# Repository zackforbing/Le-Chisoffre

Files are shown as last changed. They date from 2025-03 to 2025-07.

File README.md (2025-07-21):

# Le-Chisoffre

chiff riff with trackpad, mouseball or rotary support, now with hotswap

don't get mad at me if these don't work, they are untested. I have zero idea what I'm doing, and your yolo to jlc is not my problem

7/21/25 case probably complete. still have to prototype though. and export/upload the files. but hey pretty pictures

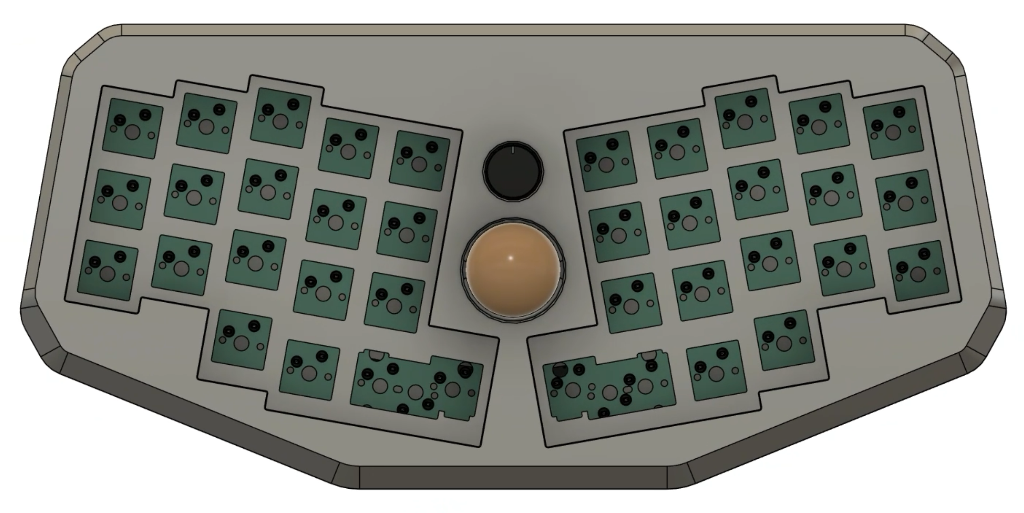
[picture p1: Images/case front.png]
case front

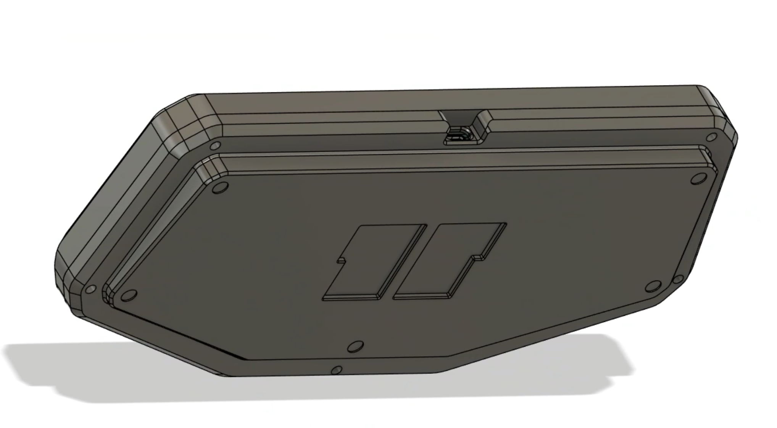
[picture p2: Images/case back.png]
case back

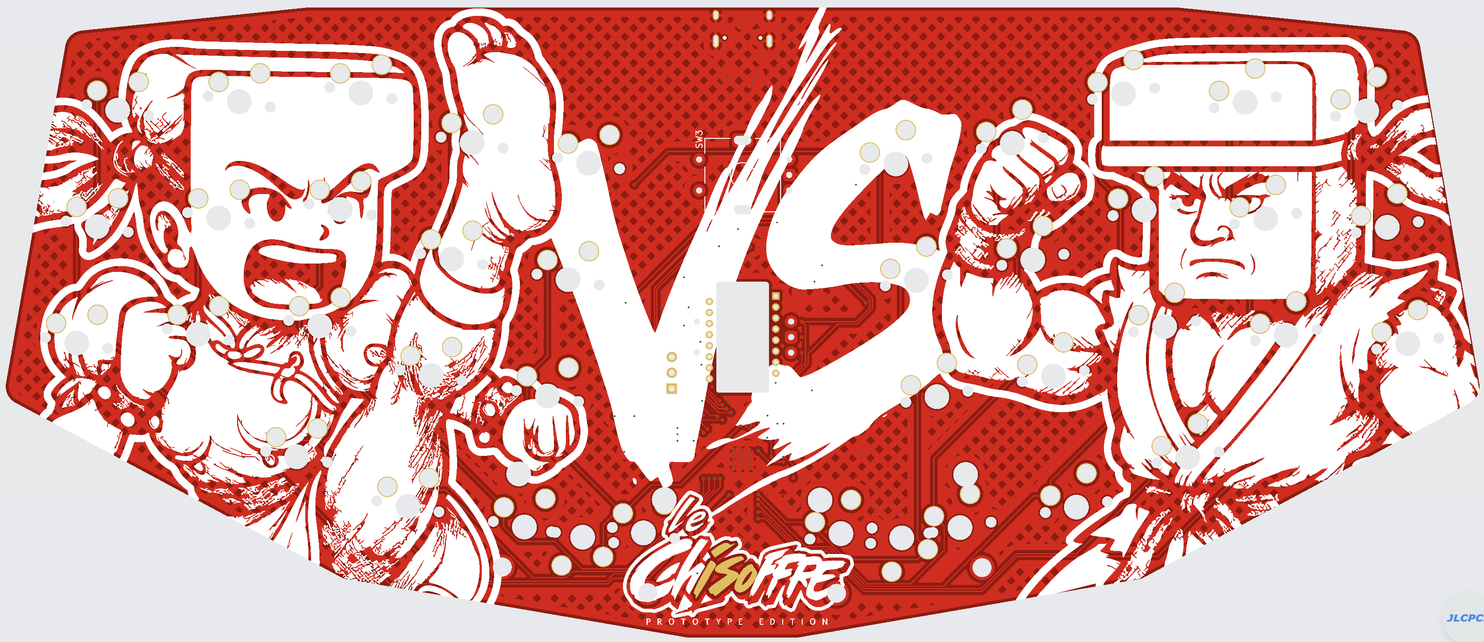
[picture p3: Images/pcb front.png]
pcb front

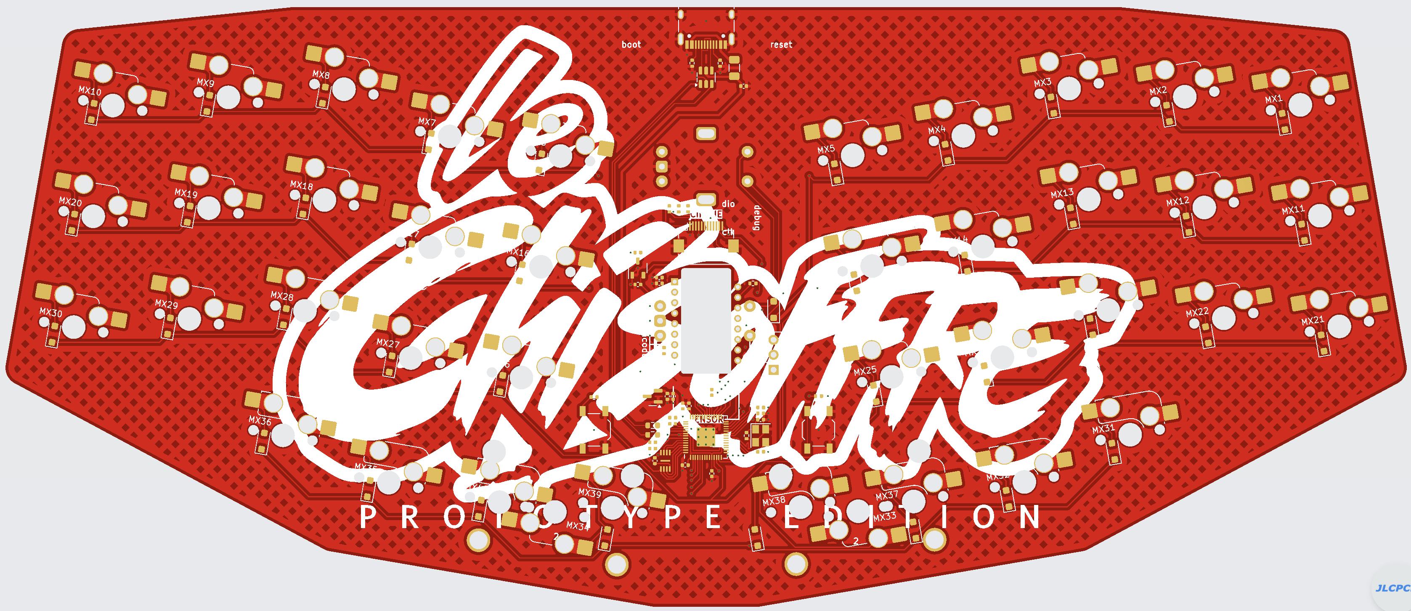
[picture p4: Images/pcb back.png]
pcb back


original readme preserved below

## Layout

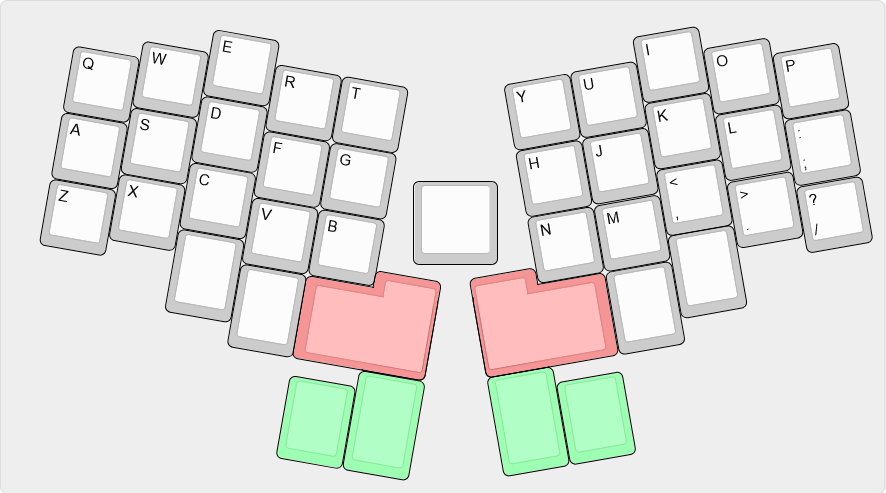
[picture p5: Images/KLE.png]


[Link](https://www.keyboard-layout-editor.com/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,%3B&@_y:-0.6399999999999997&x:0.25%3B&=N&=M&_x:1%3B&=%3E%0A.%3B&@_y:-0.75&x:4.25%3B&=%3F%0A%2F%2F%3B&@_y:-0.6200000000000001&x:2.25&a:7&h:1.25%3B&=%3B&@_y:-0.6299999999999999&x:1.25&h:1.25%3B&=%3B&@_y:0.22999999999999954&x:-0.75&c=%239cffb2&h:1.5%3B&=%3B&@_y:-0.75&x:0.25&h:1.25%3B&=)

## Todo

- [ ] order & test pcb
- [ ] create firmware
- [x] create case

## Disclaimer

Please note that this project is a work in progress with no guarantees of a working outcome. No-one involved in this project is responsible for any usage issues that may arise. However, feel free to edit, modify and otherwise utilise these files.

## License

This project is released under the GPL v3 License. Please refer to the LICENCE file.

## Credits

As always big thanks to the many people who helped me and inspired this board!

Any questions, contact Calvin0563 on Discord.

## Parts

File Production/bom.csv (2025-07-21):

Designator | Footprint | Quantity | Value | LCSC Part #
C1 | 0402 | 1 | 100n | C1525
C10, C11, C12, C13, C14, C15, C5, C6, C9 | 0402 | 9 | 100nF | C1525
C16, C17, C4, C8 | 0402 | 4 | 1uF | C52923
C18, C20, C21 | 0402 | 3 | 4u7 | C23733
C19 | 0402 | 1 | 100n | C307331
C2, C3 | 0402 | 2 | 22pF | C1555
C7 | 0402 | 1 | 10uF | C15525
D1, D10, D11, D12, D13, D14, D15, D16, D17, D18, D19, D2, D20, D21, D22, D23, D24, D25, D26, D27, D28, D29, D3, D30, D31, D32, D35, D36, D37, D38, D39, D4, D40, D41, D5, D6, D7, D8, D9 | D_SOD-123F | 39 | D_Small
F1 | 1206 | 1 | 500mA | C70076
IC1 | SON50P300X200X60-9N | 1 | W25Q16JVUXIQ | C2843335
J1 | USB_C_Receptacle_HRO_TYPE-C-31-M-12 | 1 | USB_C_Receptacle_USB2.0 | C165948
J2 | VIK_Cirque_Horizontal | 1 | VIK Cirque Connector | C88360
MX1, MX10, MX11, MX12, MX13, MX14, MX15, MX16, MX17, MX18, MX19, MX2, MX20, MX21, MX22, MX23, MX24, MX25, MX26, MX27, MX28, MX29, MX3, MX30, MX33, MX34, MX4, MX5, MX6, MX7, MX8, MX9 | flipped | 32 | MX_SW_solder
MX31, MX32, MX35, MX36, MX37, MX40 | flipped mx hs 1.25u vert | 6 | MX_SW_solder
MX38, MX39 | sw mx hs back 1.5 vert | 2 | MX_SW_solder
R10 | 0402 | 1 | 39 | C25164
R11, R9 | 0402 | 2 | 10k | C25744
R12, R13 | 0402 | 2 | 4k7 | C25900
R2 | 0402 | 1 | 1k | C25543
R3, R4 | 0402 | 2 | 5k1 | C25905
R5 | 0402 | 1 | 5.1k
R6 | 0402 | 1 | 1k | C11702
R7, R8 | 0603 | 2 | 27R | C25190
S1, S2 | STAB_MX_P_ISO | 2 | MX_stab
SW1 | SW_SPST_TL3342 | 1 | boot | C115351
SW2, SW3 | ROT_Alps_EC11E-Switch | 2 | RotaryEncoder_Switch
SWD1 | PinHeader_1x03_P2.54mm_Vertical | 1 | Conn_01x03_Female
SWR1 | SW_SPST_TL3342 | 1 | Reset
U1 | SOT-23-6 | 1 | USBLC6-2SC6 | C2827654
U2 | SOT-23 | 1 | XC6206PxxxMR-Regulator_Linear | C5446
U3 | RP2040-QFN-56 | 1 | RP2040 | C2040
U4 | SOT-23-3 | 1 | XC6206P202MR | C2891260
U5 | PMW3360 | 1 | PMW3360DM-T2QU_1
Y1 | Crystal_SMD_3225-4Pin_3.2x2.5mm | 1 | 12MHz | C9002

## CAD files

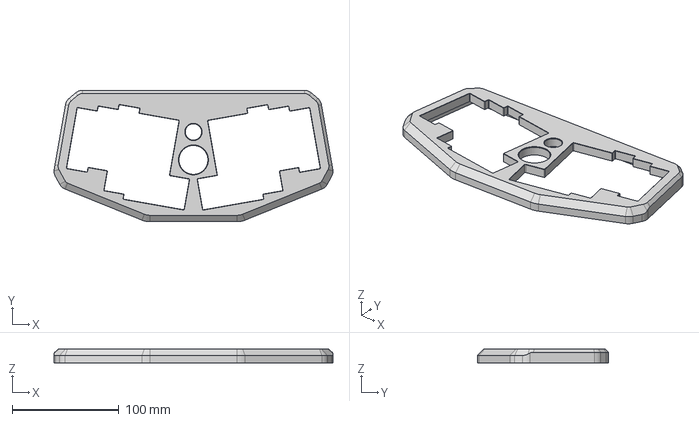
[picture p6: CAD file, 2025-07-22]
case/Le Chisoffre case revision v6 dual encoder top.step
260.8 x 122.9 x 13.0 mm

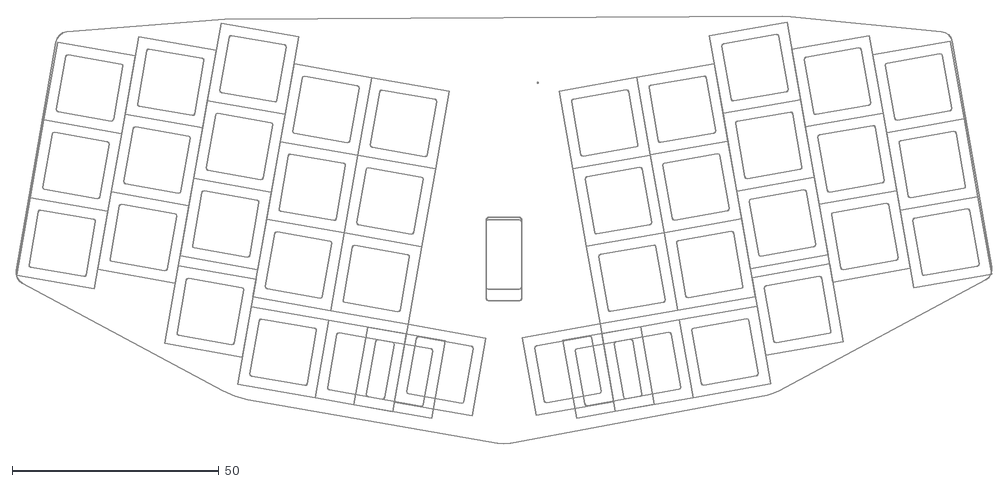
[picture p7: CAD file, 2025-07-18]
Images/Le Chisoffre-Edge_Cuts.dxf
235.8 x 103.3

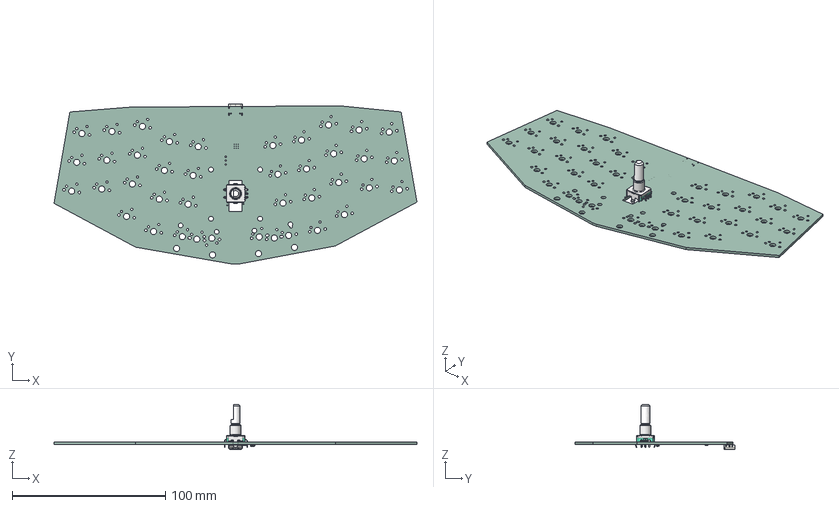
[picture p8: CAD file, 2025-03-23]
Project/Le Chisoffre.step
236.5 x 104.6 x 29.6 mm
(Unsaved)
W25X40CLUXIG TR
USB_C_Receptacle_16P_TopMnt_Horizontal_GCT_USB4105-xx-A
SOT_23
Le Chisoffre_PCB

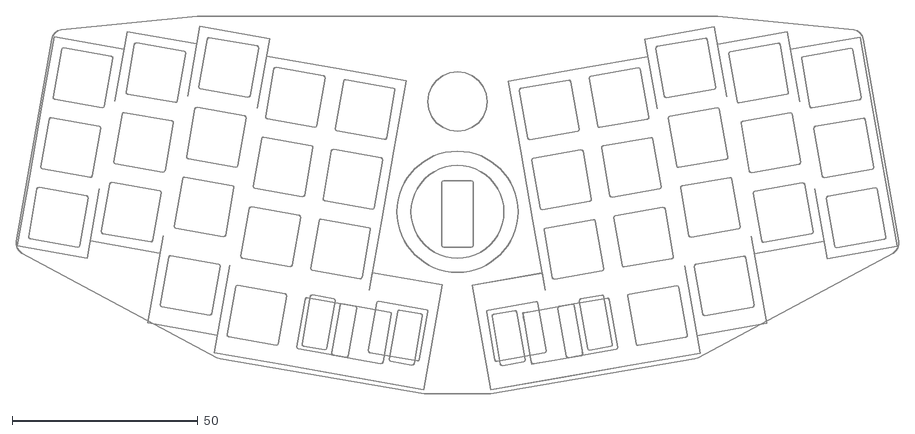
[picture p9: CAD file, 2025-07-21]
Project/Production/Le Chisoffre-Edge_Cuts.dxf
237.4 x 101.6

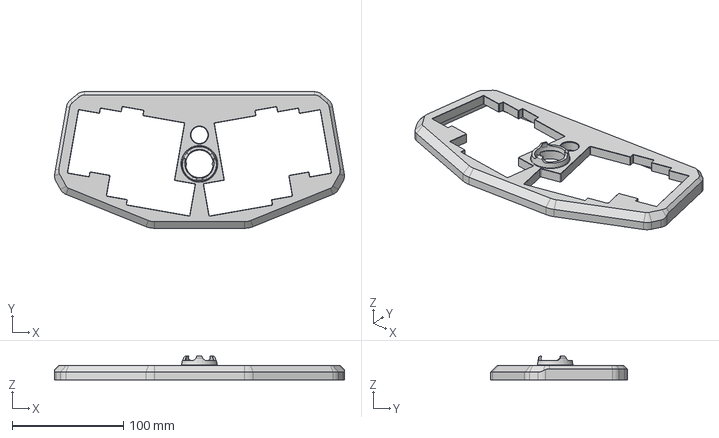
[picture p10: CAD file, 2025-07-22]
case/Le Chisoffre case revision v6 top.step
260.8 x 122.9 x 21.5 mm

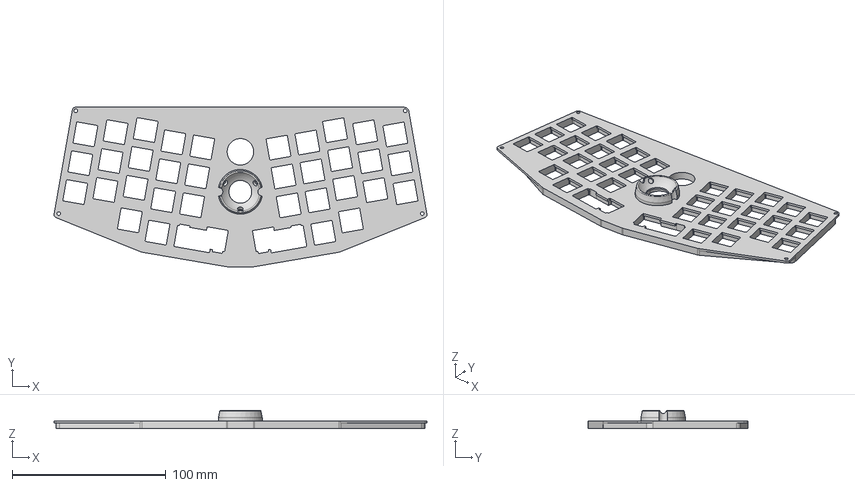
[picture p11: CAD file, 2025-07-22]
case/Le Chisoffre case revision v6 plate.step
242.2 x 103.6 x 11.8 mm

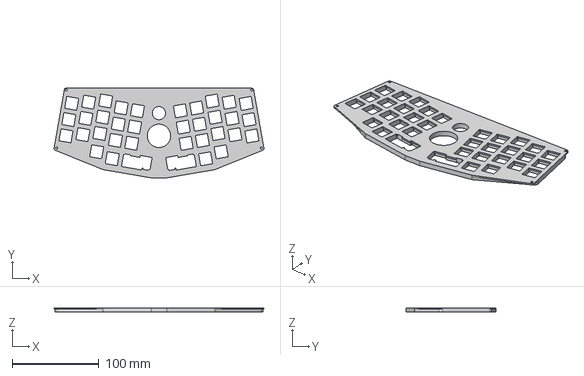
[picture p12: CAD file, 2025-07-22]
case/Le Chisoffre case revision v6 dual encoder plate.step
242.2 x 103.6 x 5.00 mm

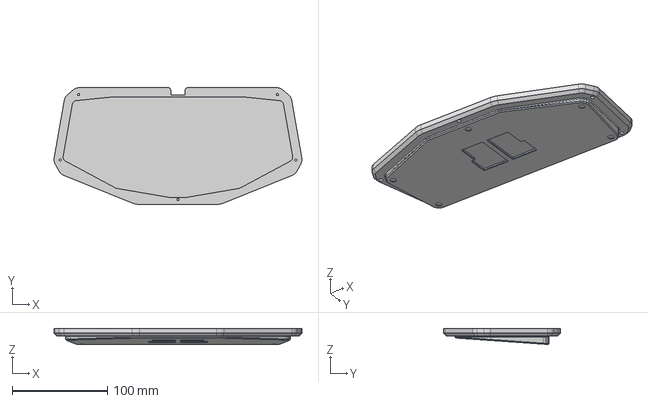
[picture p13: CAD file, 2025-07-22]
case/Le Chisoffre case revision v6 bottom.step
260.8 x 122.9 x 16.8 mm

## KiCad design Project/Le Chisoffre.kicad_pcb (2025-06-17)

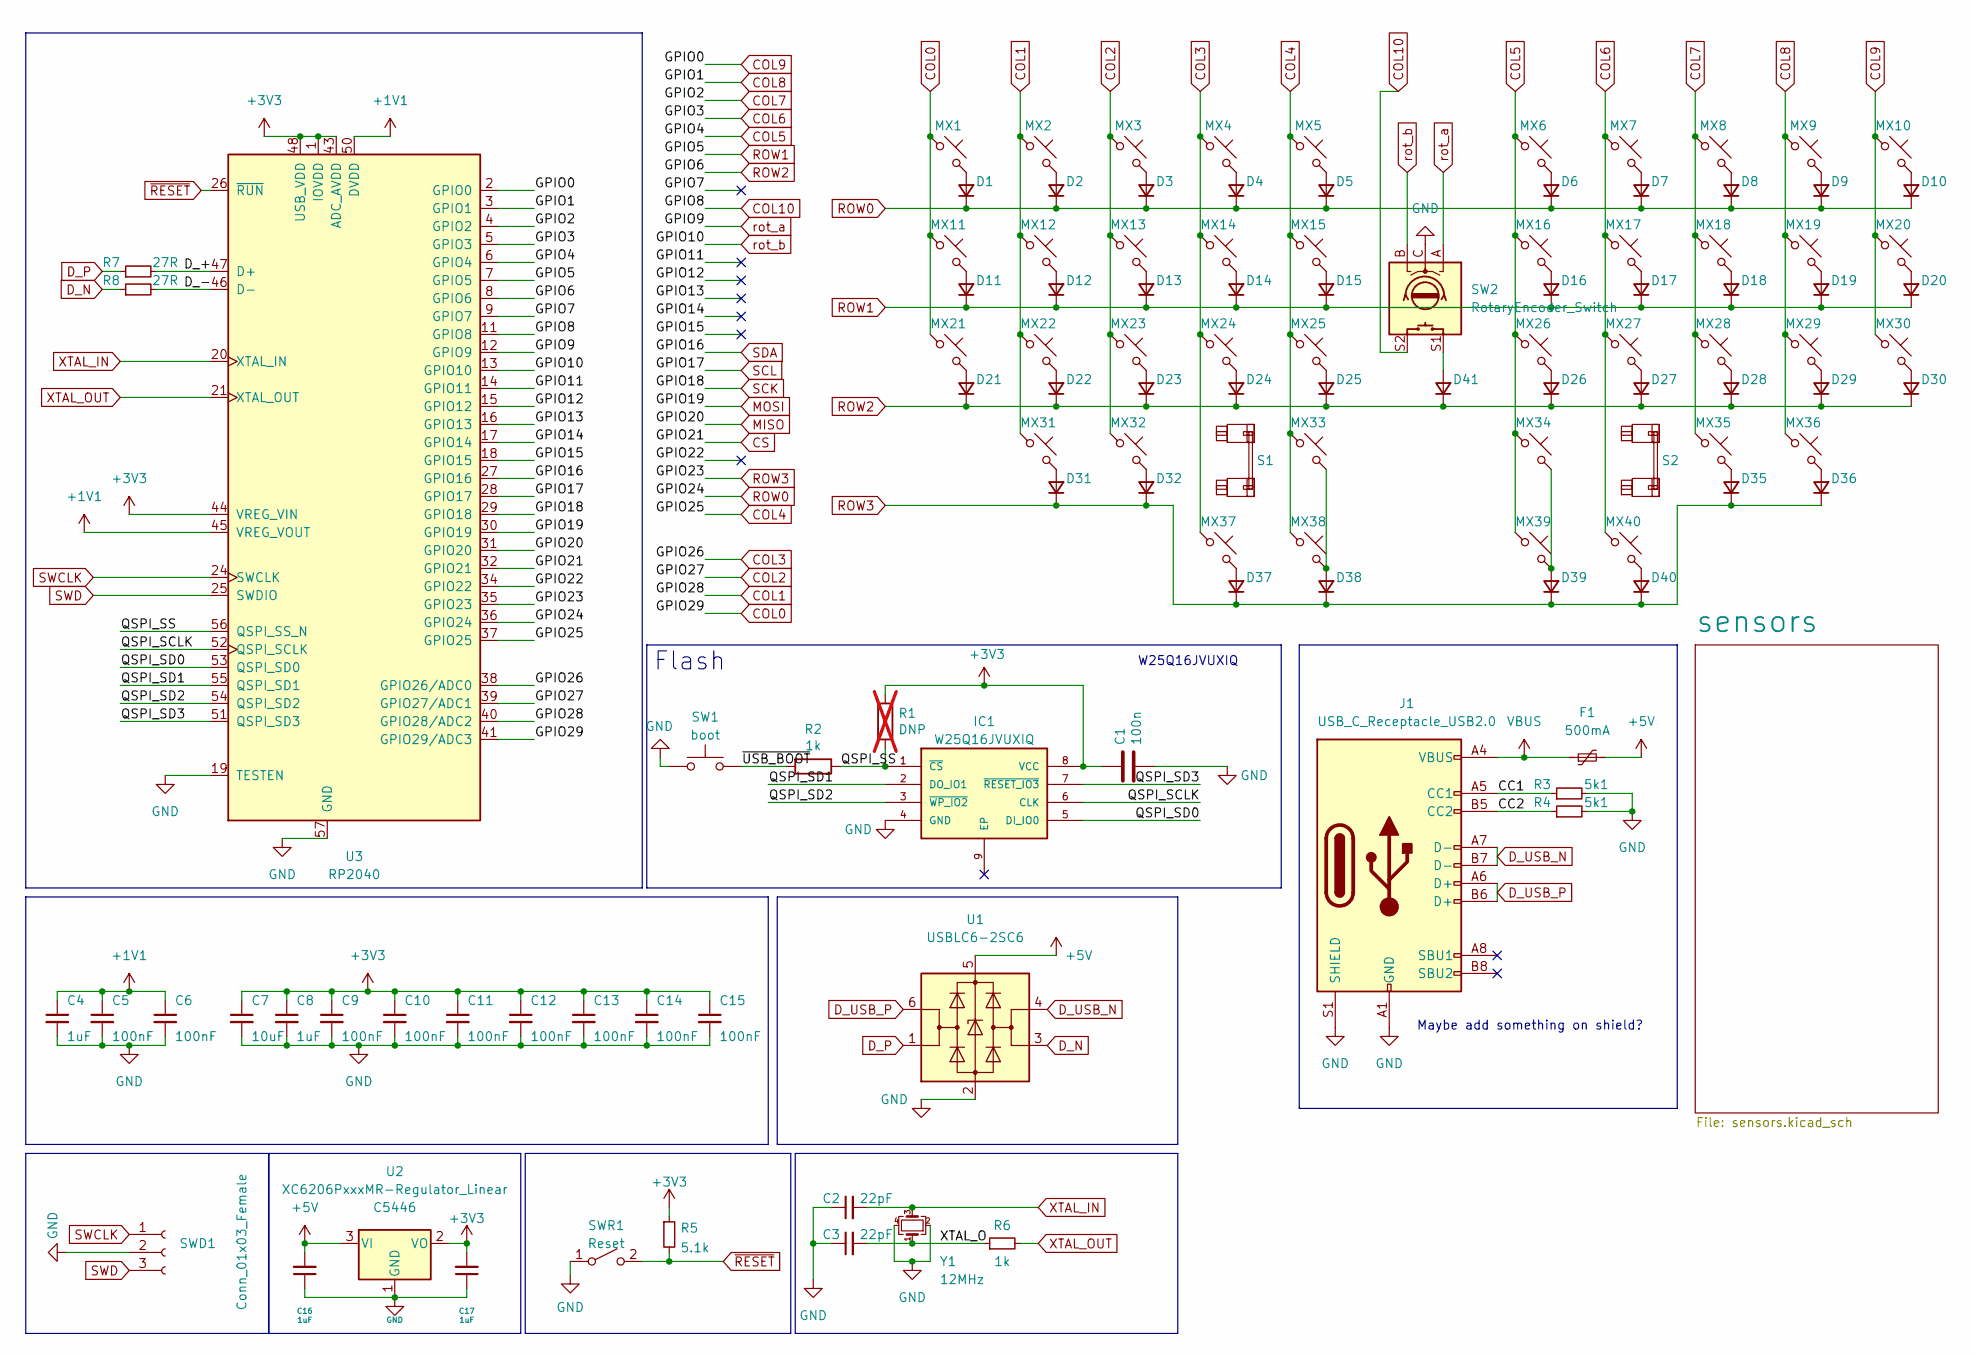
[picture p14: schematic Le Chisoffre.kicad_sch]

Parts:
C1: 100n; C_0402_1005Metric; LCSC C1525
C2, C3: 22pF; C_0402_1005Metric; LCSC C1555
C4, C8, C16, C17: 1uF; C_0402_1005Metric; LCSC C52923
C5, C6, C9, C10, C11, C12, C13, C14, C15: 100nF; C_0402_1005Metric; LCSC C1525
C7: 10uF; C_0402_1005Metric; LCSC C15525
D1, D2, D3, D4, D5, D6, D7, D8, D9, D10, D11, D12, D13, D14, D15, D16, D17, D18, D19, D20, D21, D22, D23, D24, D25, D26, D27, D28, D29, D30, D31, D32, D35, D36, D37, D38, D39, D40, D41: D_Small; D_SOD-123F
F1: 500mA; Fuse_1206_3216Metric; LCSC C70076
IC1: W25Q16JVUXIQ; SON50P300X200X60-9N; MANUFACTURER_PART_NUMBER W25Q16JVUXIQ; LCSC Part C2843335
J1: USB_C_Receptacle_USB2.0; USB_C_Receptacle_HRO_TYPE-C-31-M-12; LCSC C165948
MX1, MX2, MX3, MX4, MX5, MX6, MX7, MX8, MX9, MX10, MX11, MX12, MX13, MX14, MX15, MX16, MX17, MX18, MX19, MX20, MX21, MX22, MX23, MX24, MX25, MX26, MX27, MX28, MX29, MX30, MX33, MX34: MX_SW_solder; SW_MX_1u
MX31, MX32, MX35, MX36, MX37, MX40: MX_SW_solder; SW_MX_1.25u
MX38, MX39: MX_SW_solder; SW_MX_1.5u
R1: DNP; C_0402_1005Metric; LCSC C25905; not fitted
R2: 1k; R_0402_1005Metric; LCSC Part C25543
R3, R4: 5k1; R_0402_1005Metric; LCSC C25905
R5: 5.1k; R_0402_1005Metric
R6: 1k; R_0402_1005Metric; LCSC C11702
R7, R8: 27R; R_0603_1608Metric; LCSC C25190
S1, S2: MX_stab; STAB_MX_P_ISO
SW1: boot; SW_SPST_TL3342; LCSC Part C115351
SW2: RotaryEncoder_Switch; ROT_Alps_EC11E-Switch
SWD1: Conn_01x03_Female; PinHeader_1x03_P2.54mm_Vertical
SWR1: Reset; SW_SPST_TL3342
U1: USBLC6-2SC6; SOT-23-6; LCSC C2827654
U2: XC6206PxxxMR-Regulator_Linear; SOT-23; LCSC C5446
U3: RP2040; RP2040-QFN-56; LCSC C2040
Y1: 12MHz; Crystal_SMD_3225-4Pin_3.2x2.5mm; LCSC C9002

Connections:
+1V1: C4.1, C5.1, C6.1, U3.23 (DVDD), U3.45 (VREG_VOUT), U3.50 (DVDD)
+3V3: C1.1, C7.1, C8.1, C9.1, C10.1, C11.1, C12.1, C13.1, C14.1, C15.1, C17.2, IC1.8 (VCC), R1.1, R5.1, U2.2 (VO), U3.1 (IOVDD), U3.10 (IOVDD), U3.22 (IOVDD), U3.33 (IOVDD), U3.42 (IOVDD), U3.43 (ADC_AVDD), U3.44 (VREG_VIN), U3.48 (USB_VDD), U3.49 (IOVDD); also elsewhere on the board
+5V: C16.2, F1.2, U1.5 (VBUS), U2.3 (VI)
/CC1: J1.A5 (CC1), R3.1
/CC2: J1.B5 (CC2), R4.1
/D_+: R7.2, U3.47 (D+)
/D_-: R8.2, U3.46 (D-)
/GPIO7: U3.9 (GPIO7)
/GPIO11: U3.14 (GPIO11)
/GPIO12: U3.15 (GPIO12)
/GPIO13: U3.16 (GPIO13)
/GPIO14: U3.17 (GPIO14)
/GPIO15: U3.18 (GPIO15)
/GPIO22: U3.34 (GPIO22)
/QSPI_SCLK: IC1.6 (CLK), U3.52 (QSPI_SCLK)
/QSPI_SD0: IC1.5 (DI_IO0), U3.53 (QSPI_SD0)
/QSPI_SD1: IC1.2 (DO_IO1), U3.55 (QSPI_SD1)
/QSPI_SD2: IC1.3 (~WP_IO2), U3.54 (QSPI_SD2)
/QSPI_SD3: IC1.7 (~RESET_IO3), U3.51 (QSPI_SD3)
/QSPI_SS: IC1.1 (~CS), R1.2, R2.1, U3.56 (QSPI_SS_N)
/XTAL_O: C3.2, R6.1, Y1.1
/~USB_BOOT: R2.2, SW1.2
COL0: MX1.1, MX11.1, MX21.1, U3.41 (GPIO29/ADC3)
COL1: MX2.1, MX12.1, MX22.1, MX31.1, U3.40 (GPIO28/ADC2)
COL2: MX3.1, MX13.1, MX23.1, MX32.1, U3.39 (GPIO27/ADC1)
COL3: MX4.1, MX14.1, MX24.1, MX37.1, U3.38 (GPIO26/ADC0)
COL4: MX5.1, MX15.1, MX25.1, MX33.1, MX38.1, U3.37 (GPIO25)
COL5: MX6.1, MX16.1, MX26.1, MX34.1, MX39.1, U3.6 (GPIO4)
COL6: MX7.1, MX17.1, MX27.1, MX40.1, U3.5 (GPIO3)
COL7: MX8.1, MX18.1, MX28.1, MX35.1, U3.4 (GPIO2)
COL8: MX9.1, MX19.1, MX29.1, MX36.1, U3.3 (GPIO1)
COL9: MX10.1, MX20.1, MX30.1, U3.2 (GPIO0)
COL10: SW2.S2, U3.11 (GPIO8)
CS: U3.32 (GPIO21); also elsewhere on the board
D_N: R8.1, U1.3 (I/O2)
D_P: R7.1, U1.1 (I/O1)
D_USB_N: J1.A7 (D-), J1.B7 (D-), U1.4 (I/O2)
D_USB_P: J1.A6 (D+), J1.B6 (D+), U1.6 (I/O1)
GND: C1.2, C2.1, C3.1, C4.2, C5.2, C6.2, C7.2, C8.2, C9.2, C10.2, C11.2, C12.2, C13.2, C14.2, C15.2, C16.1, C17.1, IC1.4 (GND), J1.A1 (GND), J1.A12 (GND), J1.B1 (GND), J1.B12 (GND), J1.S1 (SHIELD), R3.2, R4.2, SW1.1, SW2.C, SWD1.2, SWR1.1 (A), U1.2 (GND), U2.1 (GND), U3.19 (TESTEN), U3.57 (GND), Y1.2, Y1.4; also elsewhere on the board
MISO: U3.31 (GPIO20); also elsewhere on the board
MOSI: U3.30 (GPIO19); also elsewhere on the board
unnamed: D1.2 (A), MX1.2
unnamed: D2.2 (A), MX2.2
unnamed: D3.2 (A), MX3.2
unnamed: D4.2 (A), MX4.2
unnamed: D5.2 (A), MX5.2
unnamed: D6.2 (A), MX6.2
unnamed: D7.2 (A), MX7.2
unnamed: D8.2 (A), MX8.2
unnamed: D9.2 (A), MX9.2
unnamed: D10.2 (A), MX10.2
unnamed: D11.2 (A), MX11.2
unnamed: D12.2 (A), MX12.2
unnamed: D13.2 (A), MX13.2
unnamed: D14.2 (A), MX14.2
unnamed: D15.2 (A), MX15.2
unnamed: D16.2 (A), MX16.2
unnamed: D17.2 (A), MX17.2
unnamed: D18.2 (A), MX18.2
unnamed: D19.2 (A), MX19.2
unnamed: D20.2 (A), MX20.2
unnamed: D21.2 (A), MX21.2
unnamed: D22.2 (A), MX22.2
unnamed: D23.2 (A), MX23.2
unnamed: D24.2 (A), MX24.2
unnamed: D25.2 (A), MX25.2
unnamed: D26.2 (A), MX26.2
unnamed: D27.2 (A), MX27.2
unnamed: D28.2 (A), MX28.2
unnamed: D29.2 (A), MX29.2
unnamed: D30.2 (A), MX30.2
unnamed: D31.2 (A), MX31.2
unnamed: D32.2 (A), MX32.2
unnamed: D35.2 (A), MX35.2
unnamed: D36.2 (A), MX36.2
unnamed: D37.2 (A), MX37.2
unnamed: D38.2 (A), MX33.2, MX38.2
unnamed: D39.2 (A), MX34.2, MX39.2
unnamed: D40.2 (A), MX40.2
unnamed: D41.2 (A), SW2.S1
ROW0: D1.1 (K), D2.1 (K), D3.1 (K), D4.1 (K), D5.1 (K), D6.1 (K), D7.1 (K), D8.1 (K), D9.1 (K), D10.1 (K), U3.36 (GPIO24)
ROW1: D11.1 (K), D12.1 (K), D13.1 (K), D14.1 (K), D15.1 (K), D16.1 (K), D17.1 (K), D18.1 (K), D19.1 (K), D20.1 (K), U3.7 (GPIO5)
ROW2: D21.1 (K), D22.1 (K), D23.1 (K), D24.1 (K), D25.1 (K), D26.1 (K), D27.1 (K), D28.1 (K), D29.1 (K), D30.1 (K), D41.1 (K), U3.8 (GPIO6)
ROW3: D31.1 (K), D32.1 (K), D35.1 (K), D36.1 (K), D37.1 (K), D38.1 (K), D39.1 (K), D40.1 (K), U3.35 (GPIO23)
SCK: U3.29 (GPIO18); also elsewhere on the board
SCL: U3.28 (GPIO17); also elsewhere on the board
SDA: U3.27 (GPIO16); also elsewhere on the board
SWCLK: SWD1.1, U3.24 (SWCLK)
SWD: SWD1.3, U3.25 (SWDIO)
VBUS: F1.1, J1.A4 (VBUS), J1.A9 (VBUS), J1.B4 (VBUS), J1.B9 (VBUS)
XTAL_IN: C2.2, U3.20 (XTAL_IN), Y1.3
XTAL_OUT: R6.2, U3.21 (XTAL_OUT)
rot_a: SW2.A, U3.12 (GPIO9)
rot_b: SW2.B, U3.13 (GPIO10)
~RESET: R5.2, SWR1.2 (B), U3.26 (~RUN)

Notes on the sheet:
W25Q16JVUXIQ
Maybe add something on shield?
Flash

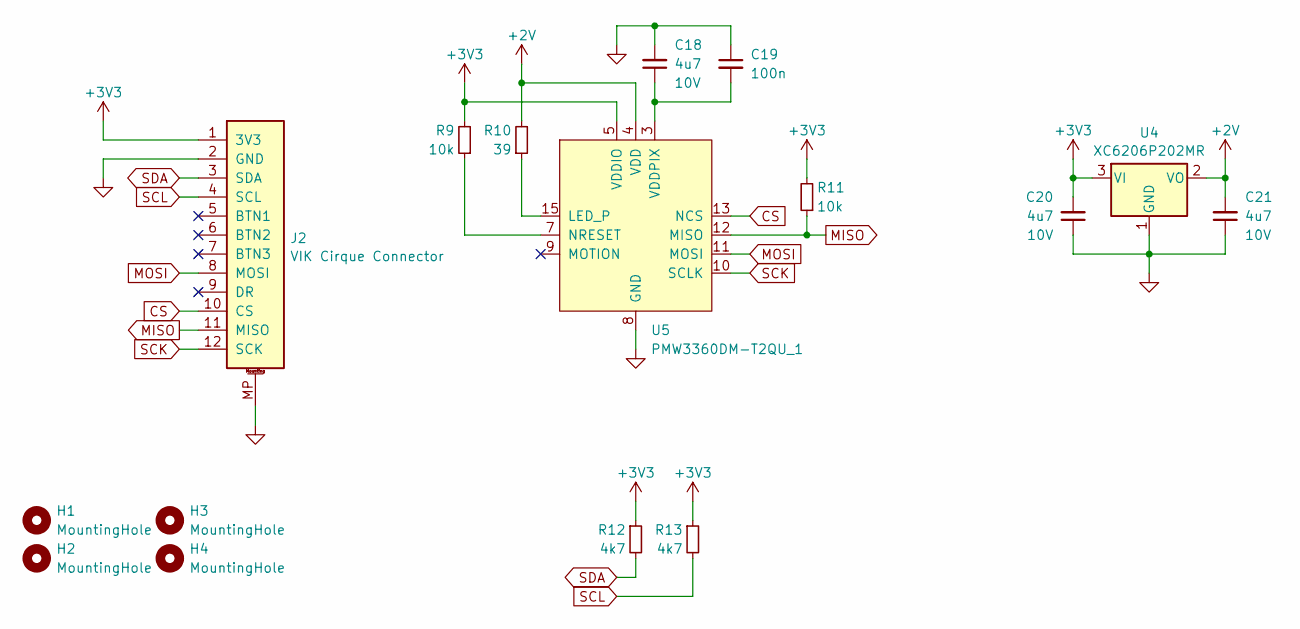
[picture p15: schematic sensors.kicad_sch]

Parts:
C18, C20, C21: 4u7; C_0402_1005Metric; Voltage 10V; LCSC C23733
C19: 100n; C_0402_1005Metric; Voltage 50V; LCSC C307331
H1, H2, H3, H4: MountingHole; MountingHole_3.2mm_M3
J2: VIK Cirque Connector; VIK_Cirque_Horizontal; LCSC C88360
R9, R11: 10k; R_0402_1005Metric; LCSC C25744
R10: 39; R_0402_1005Metric; LCSC C25164
R12, R13: 4k7; R_0402_1005Metric; LCSC C25900
U4: XC6206P202MR; SOT-23-3; LCSC C2891260
U5: PMW3360DM-T2QU_1; PixArt_PMW3360DM-T2QU

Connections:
+2V: C21.2, R10.2, U4.2 (VO), U5.4 (VDD)
+3V3: C20.2, J2.1 (3V3), R9.2, R11.2, R12.1, R13.1, U4.3 (VI), U5.5 (VDDIO); also elsewhere on the board
CS: J2.10 (CS), U5.13 (NCS); also elsewhere on the board
GND: C18.2, C19.1, C20.1, C21.1, J2.2 (GND), J2.MP, U4.1 (GND), U5.8 (GND); also elsewhere on the board
MISO: J2.11 (MISO), R11.1, U5.12 (MISO); also elsewhere on the board
MOSI: J2.8 (MOSI), U5.11 (MOSI); also elsewhere on the board
unnamed: R10.1, U5.15 (LED_P)
unnamed: R9.1, U5.7 (NRESET)
unnamed: C18.1, C19.2, U5.3 (VDDPIX)
SCK: J2.12 (SCK), U5.10 (SCLK); also elsewhere on the board
SCL: J2.4 (SCL), R13.2; also elsewhere on the board
SDA: J2.3 (SDA), R12.2; also elsewhere on the board

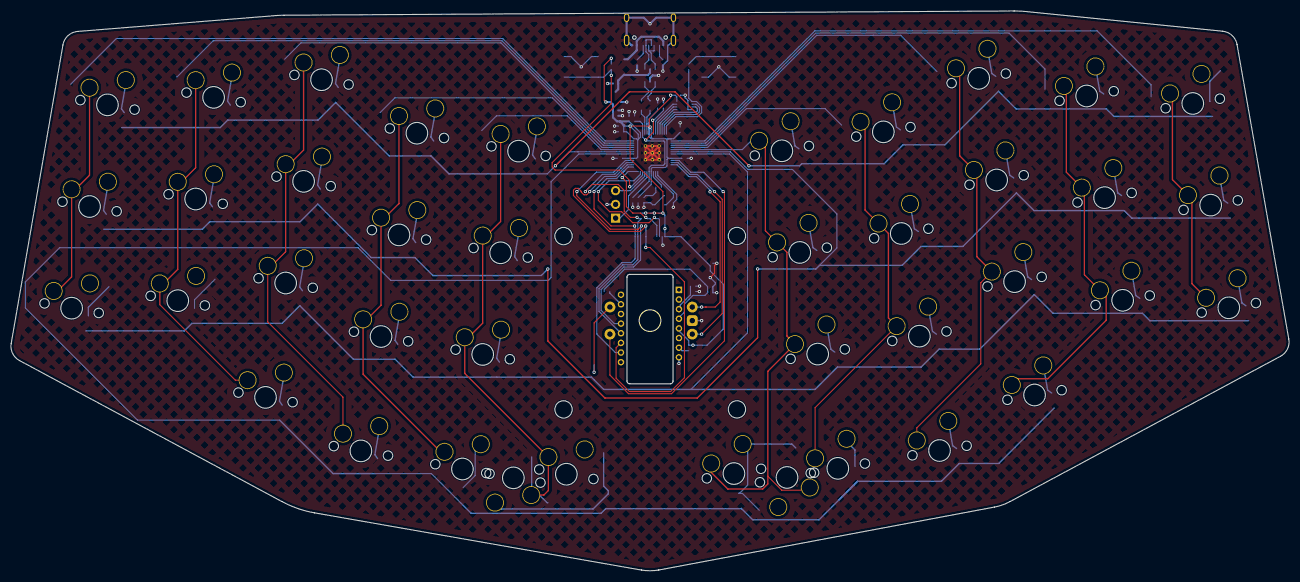
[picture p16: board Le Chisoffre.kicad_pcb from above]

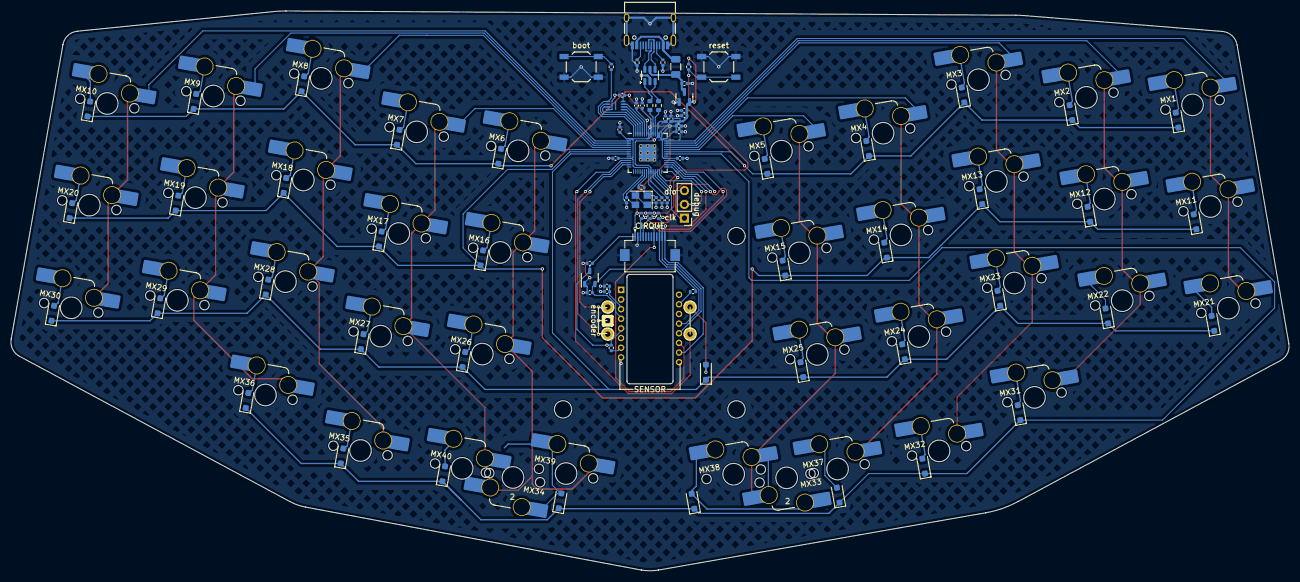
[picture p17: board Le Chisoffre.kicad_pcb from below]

Board: 2 copper layers, 235.9 x 103.3 mm, 130 parts (85 on the bottom side), 92 nets.

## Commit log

2025-03-22 wip update
    [Le Chisoffre.kicad_pcb, Le Chisoffre.kicad_sch, sensors.kicad_sch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]
2025-03-23 update
    first full version done
    [Le Chisoffre-B_Cu.gbr, Le Chisoffre-B_Mask.gbr, Le Chisoffre-B_Paste.gbr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]
2025-03-23 clean up
    [Le Chisoffre.kicad_pcb]
2025-06-17 pcb finalized, cleanup necessary
    [Le Chisoffre.kicad_pcb, designators.csv]
2025-06-18 added silk, new gerbs
    [bom.csv, positions.csv]
2025-07-18 moved trackball, rerouted
    [Le Chisoffre-Edge_Cuts.dxf, bom.csv, designators.csv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]
2025-07-20 moved mcu, added extra encoder location
    [Le Chisoffre-mcu.kicad_sch, Le Chisoffre.kicad_sch, Le Chisoffre_old.kicad_sch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]
2025-07-21 clearing old files, symmetric edge cuts
    [BOM-Le Chisoffre.csv, Le Chisoffre-Edge_Cuts.dxf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]
2025-07-21 updated readme, added edge cuts for plate
    [Le Chisoffre-Edge_Cuts.dxf]
2025-07-21 moved upper encoder down
    [Le Chisoffre-Edge_Cuts.dxf, bom.csv, designators.csv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]
2025-08-03 moving things
    [Le Chisoffre.kicad_sch, bom.csv, designators.csv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]
